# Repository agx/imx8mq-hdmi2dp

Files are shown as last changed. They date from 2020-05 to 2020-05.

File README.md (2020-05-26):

# HDMI to DP adapter for imx8mq

The imx8mq can output HDMI 2.0a or eDP/DP via it's HDMI TX. 
In order to test DisplayPort with a board that's designed
for HDMI one can use this adapter board. For this to work
you need to

- remove pull downs from the HDMI lanes. That's R1901-R1908 on the [Librem5 devkit][]
- use the DisplayPort instead of the HDMI firmware in uboot
  from https://www.nxp.com/lgfiles/NMG/MAD/YOCTO/firmware-imx-8.7.bin
- configure the Linux kernel for DP instead of HDMI for the cadence bridge
  as used in NXPs BSP:
  
```
&hdmi {
        compatible = "cdn,imx8mq-dp";
        lane-mapping = <0xc6>;
        status = "okay";
        port@1 {
                hdmi_in: endpoint {
                        remote-endpoint = <&dcss_out>;
                };
        };
};
```

The schematics for this kind of adapter were initially pubilshed by Bernhard
Fink from NXPs forum at https://community.nxp.com/thread/491629 .

[Librem5 devkit]: https://source.puri.sm/Librem5/dvk-mx8m-bsb

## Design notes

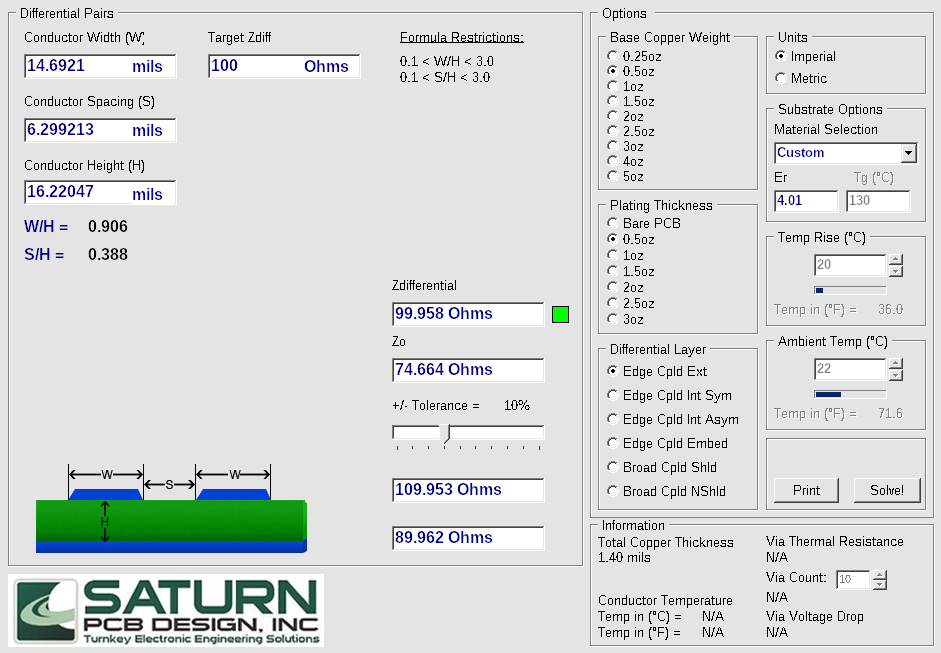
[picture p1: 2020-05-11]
calculations/saturn.png

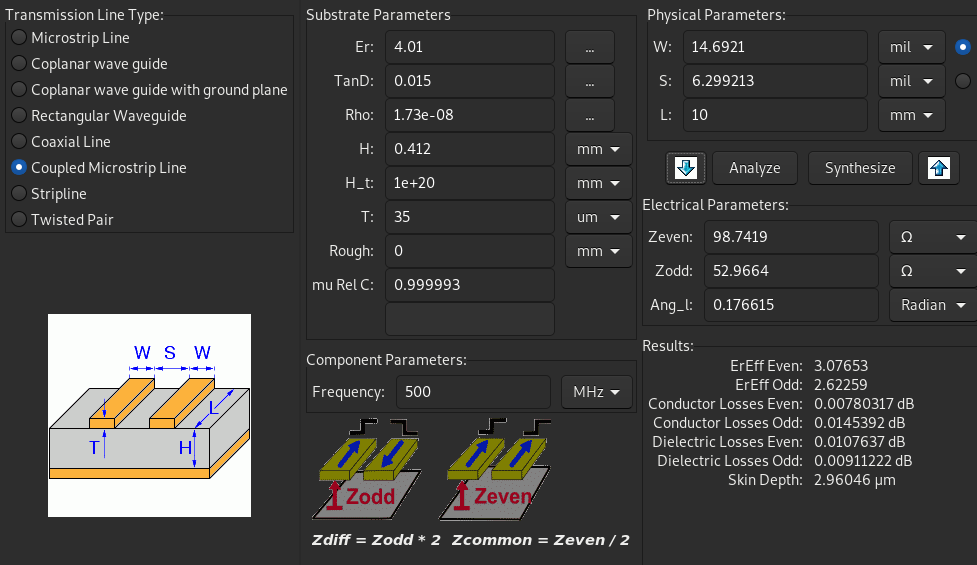
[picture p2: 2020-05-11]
calculations/kicad.png

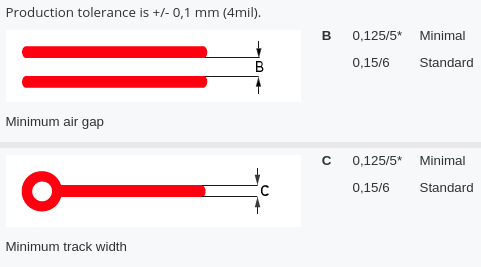
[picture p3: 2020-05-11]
calculations/minimum_trace_width_space.png

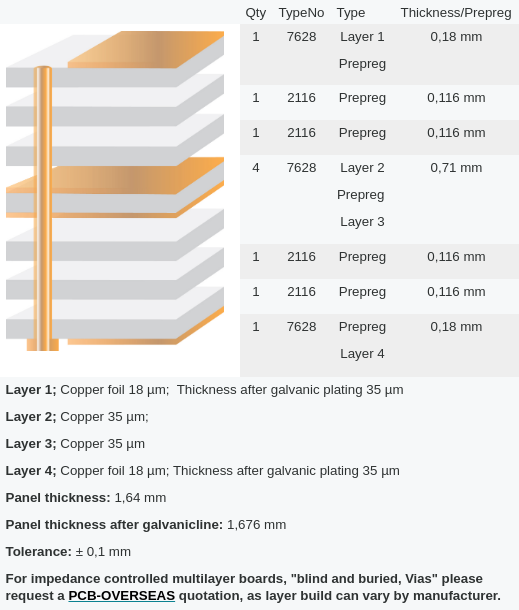
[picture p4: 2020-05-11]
calculations/stackup.png

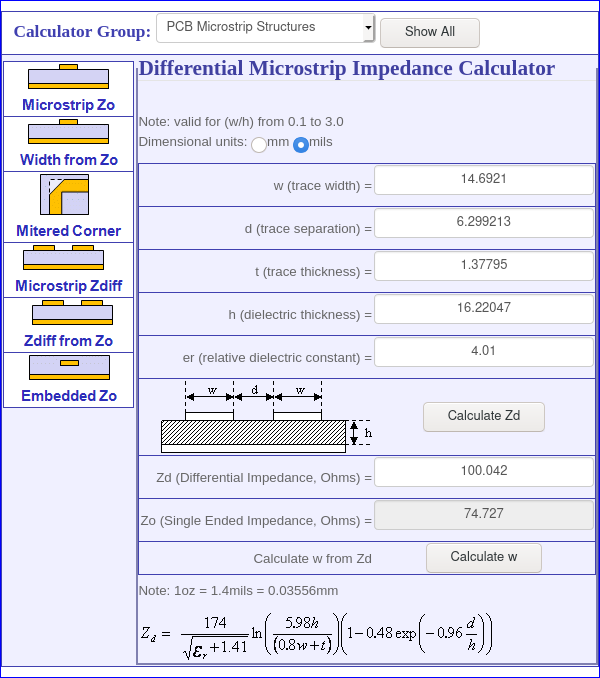
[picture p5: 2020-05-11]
calculations/mantaro.png

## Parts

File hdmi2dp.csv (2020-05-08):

Id | Designator | Package | Quantity | Designation | Supplier and ref
1 | J1 | AMPHENOL_10029449-001RLF | 1 | HDMI_A
2 | C1,C2,C3,C4,C6,C7,C8,C9,C10,C12,C13,C15,C16 | C_1206_3216Metric_Pad1.42x1.75mm_HandSolder | 13 | 0,1uF
3 | C5,C14 | C_1206_3216Metric_Pad1.42x1.75mm_HandSolder | 2 | 22uF
4 | C11 | C_1206_3216Metric_Pad1.42x1.75mm_HandSolder | 1 | 10uF
5 | J2 | MOLEX_47272-0001 | 1 | 47272-0001
6 | R1,R2,R6 | R_1206_3216Metric_Pad1.42x1.75mm_HandSolder | 3 | 1M
7 | U1 | SOT-223-3_TabPin2 | 1 | AMS1117-3.3
8 | C17 | C_1206_3216Metric_Pad1.42x1.75mm_HandSolder | 1 | 1uF
9 | R3,R7,R8 | R_1206_3216Metric_Pad1.42x1.75mm_HandSolder | 3 | >100K
10 | R4,R5 | R_1206_3216Metric_Pad1.42x1.75mm_HandSolder | 2 | 100K

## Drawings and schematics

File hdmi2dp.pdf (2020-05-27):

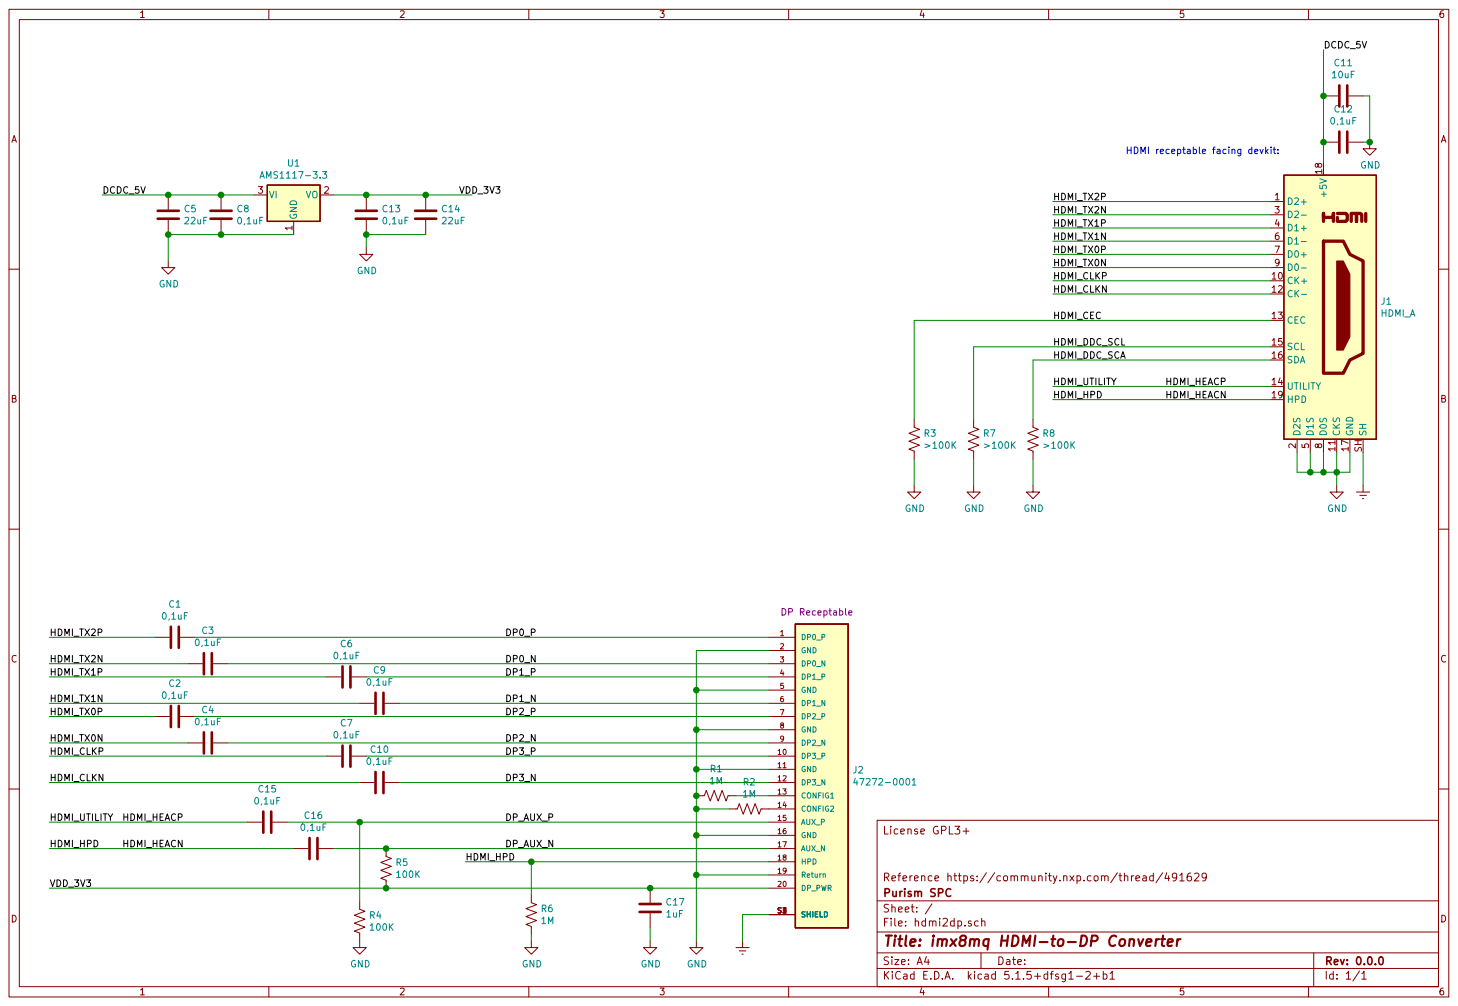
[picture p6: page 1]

HDMI receptable facing devkit:

Reference https://community.nxp.com/thread/491629
File: hdmi2dp.sch Sheet: / Purism SPC

Id: 1/1 Title: imx8mq HDMI-to-DP Converter

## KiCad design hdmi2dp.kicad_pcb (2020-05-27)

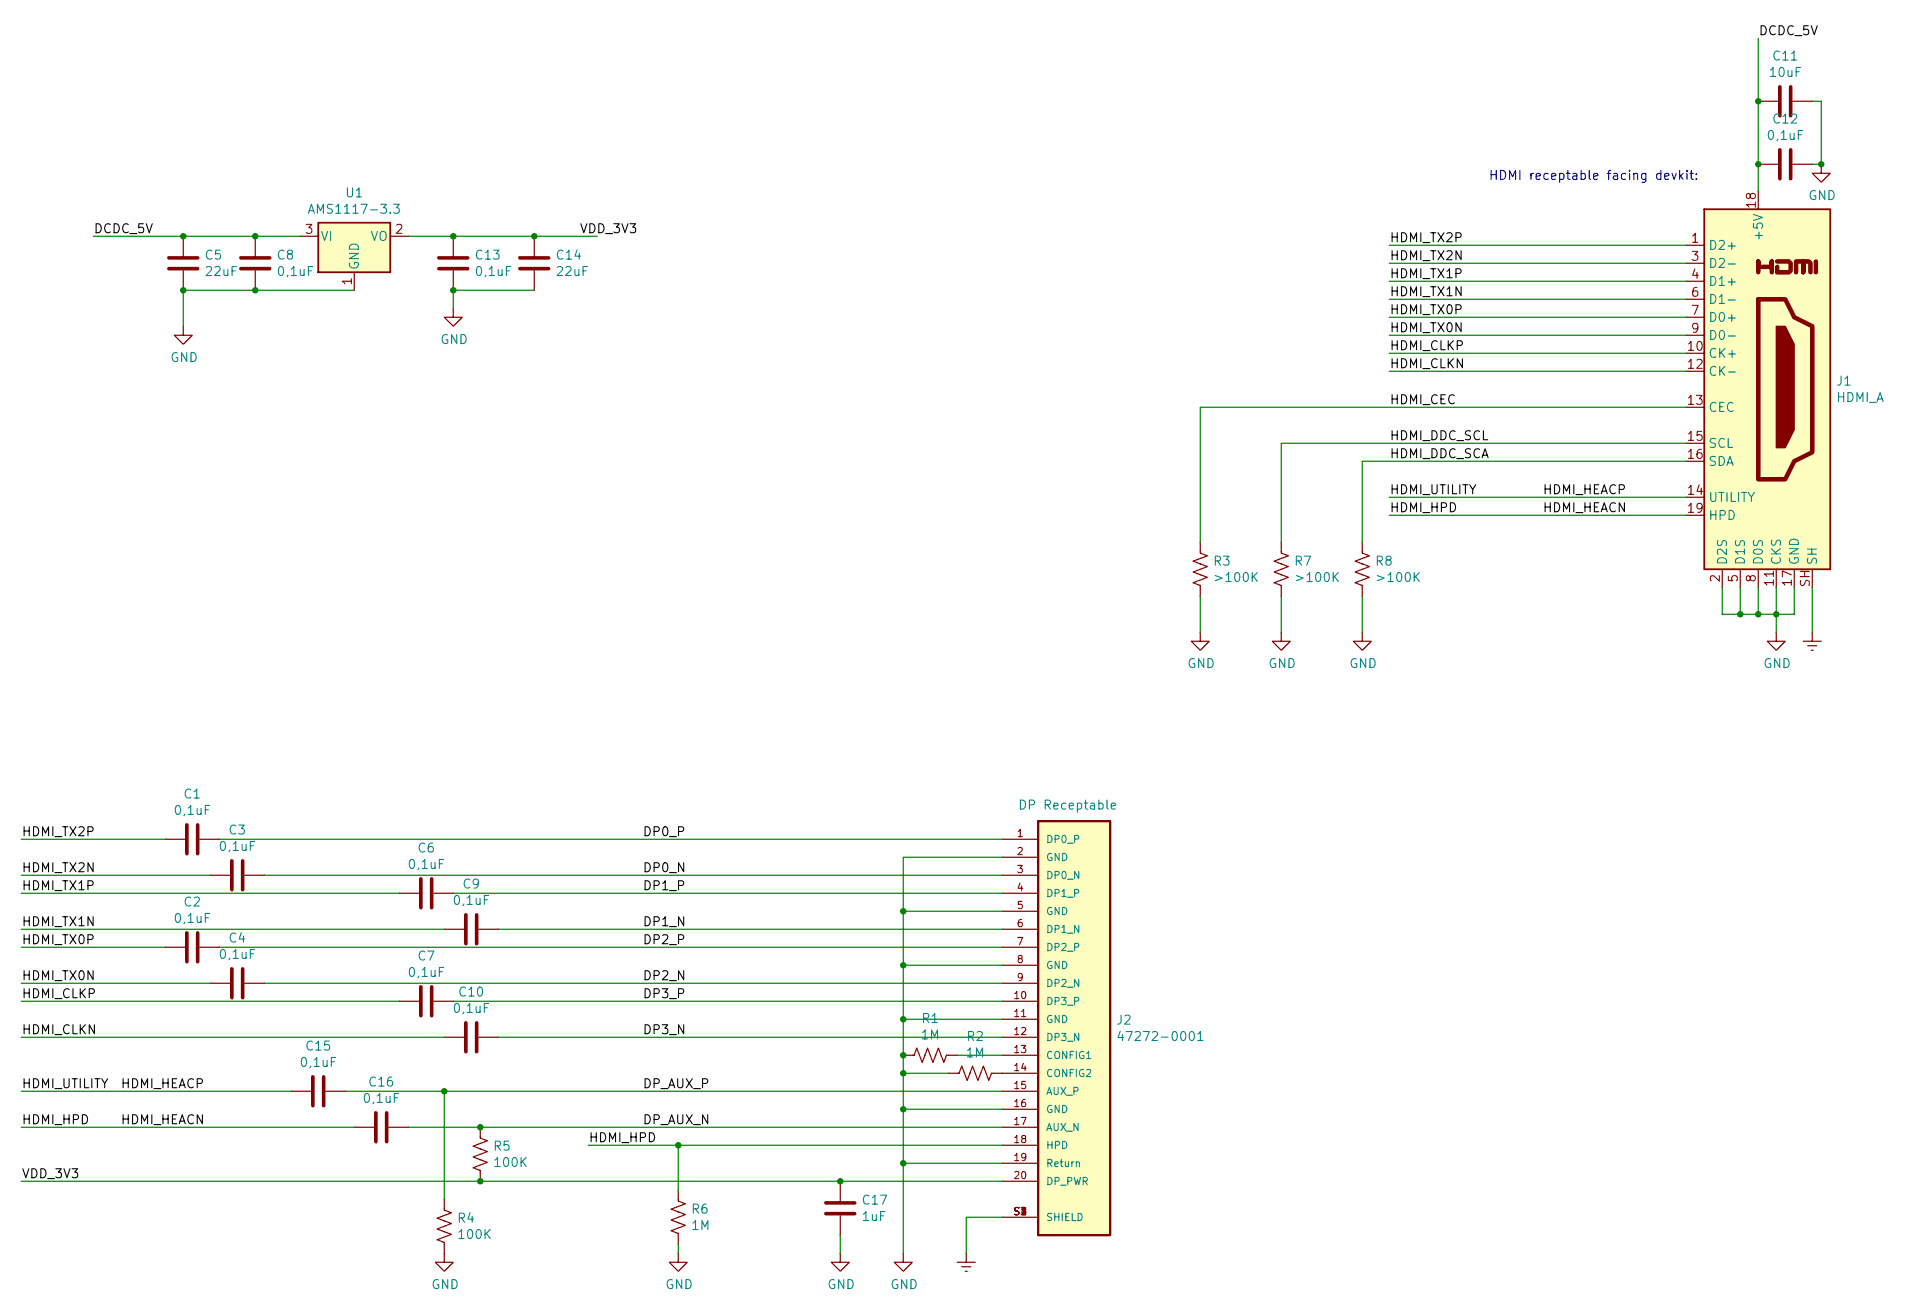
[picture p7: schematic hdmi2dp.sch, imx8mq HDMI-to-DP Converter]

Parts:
C1, C2, C3, C4, C6, C7, C8, C9, C10, C12, C13, C15, C16: 0,1uF; C_1206_3216Metric_Pad1.42x1.75mm_HandSolder
C5, C14: 22uF; C_1206_3216Metric_Pad1.42x1.75mm_HandSolder
C11: 10uF; C_1206_3216Metric_Pad1.42x1.75mm_HandSolder
C17: 1uF; C_1206_3216Metric_Pad1.42x1.75mm_HandSolder
J1: HDMI_A; AMPHENOL_10029449-001RLF
J2: 47272-0001; MOLEX_47272-0001
R1, R2, R6: 1M; R_1206_3216Metric_Pad1.42x1.75mm_HandSolder
R3, R7, R8: >100K; R_1206_3216Metric_Pad1.42x1.75mm_HandSolder
R4, R5: 100K; R_1206_3216Metric_Pad1.42x1.75mm_HandSolder
U1: AMS1117-3.3; SOT-223-3_TabPin2

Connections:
/DCDC_5V: C5.1, C8.1, C11.2, C12.2, J1.18 (+5V), U1.3 (VI)
/DP0_N: C3.1, J2.3 (DP0_N)
/DP0_P: C1.1, J2.1 (DP0_P)
/DP1_N: C9.1, J2.6 (DP1_N)
/DP1_P: C6.1, J2.4 (DP1_P)
/DP2_N: C4.1, J2.9 (DP2_N)
/DP2_P: C2.1, J2.7 (DP2_P)
/DP3_N: C10.1, J2.12 (DP3_N)
/DP3_P: C7.1, J2.10 (DP3_P)
/DP_AUX_N: C16.1, J2.17 (AUX_N), R5.1
/DP_AUX_P: C15.1, J2.15 (AUX_P), R4.1
/HDMI_CEC: J1.13 (CEC), R3.1
/HDMI_CLKN: C10.2, J1.12 (CK-)
/HDMI_CLKP: C7.2, J1.10 (CK+)
/HDMI_DDC_SCA: J1.16 (SDA), R8.1
/HDMI_DDC_SCL: J1.15 (SCL), R7.1
/HDMI_HEACN: C16.2, J1.19 (HPD), J2.18 (HPD), R6.1
/HDMI_HEACP: C15.2, J1.14 (UTILITY)
/HDMI_TX0N: C4.2, J1.9 (D0-)
/HDMI_TX0P: C2.2, J1.7 (D0+)
/HDMI_TX1N: C9.2, J1.6 (D1-)
/HDMI_TX1P: C6.2, J1.4 (D1+)
/HDMI_TX2N: C3.2, J1.3 (D2-)
/HDMI_TX2P: C1.2, J1.1 (D2+)
/VDD_3V3: C13.1, C14.1, C17.1, J2.20 (DP_PWR), R5.2, U1.2 (VO)
Earth: J1.S1, J1.S2, J1.S3, J1.S4, J1.SH, J2.S1 (SHIELD), J2.S2 (SHIELD), J2.S3 (SHIELD), J2.S4 (SHIELD)
GND: C5.2, C8.2, C11.1, C12.1, C13.2, C14.2, C17.2, J1.2 (D2S), J1.5 (D1S), J1.8 (D0S), J1.11 (CKS), J1.17 (GND), J2.2 (GND), J2.5 (GND), J2.8 (GND), J2.11 (GND), J2.16 (GND), J2.19 (Return), R1.2, R2.2, R3.2, R4.2, R6.2, R7.2, R8.2, U1.1 (GND)
unnamed: J2.13 (CONFIG1), R1.1
unnamed: J2.14 (CONFIG2), R2.1

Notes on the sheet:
HDMI receptable facing devkit:

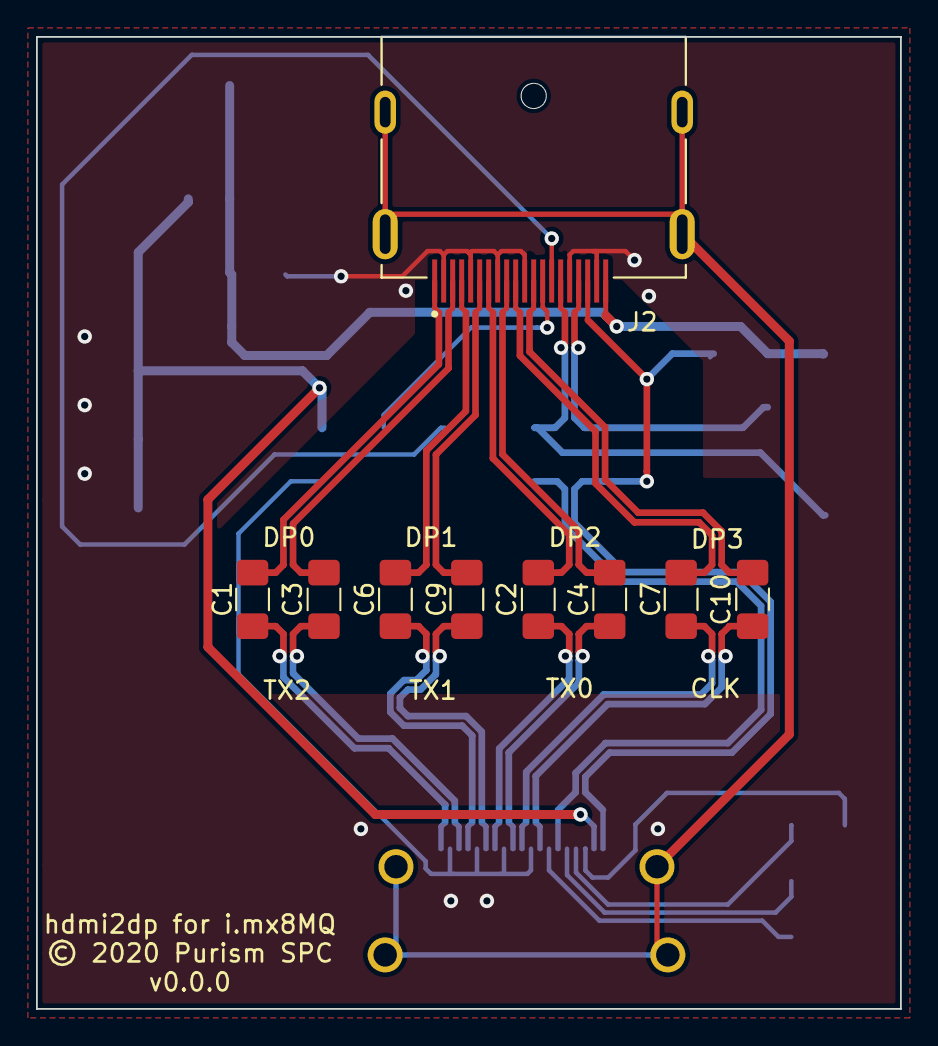
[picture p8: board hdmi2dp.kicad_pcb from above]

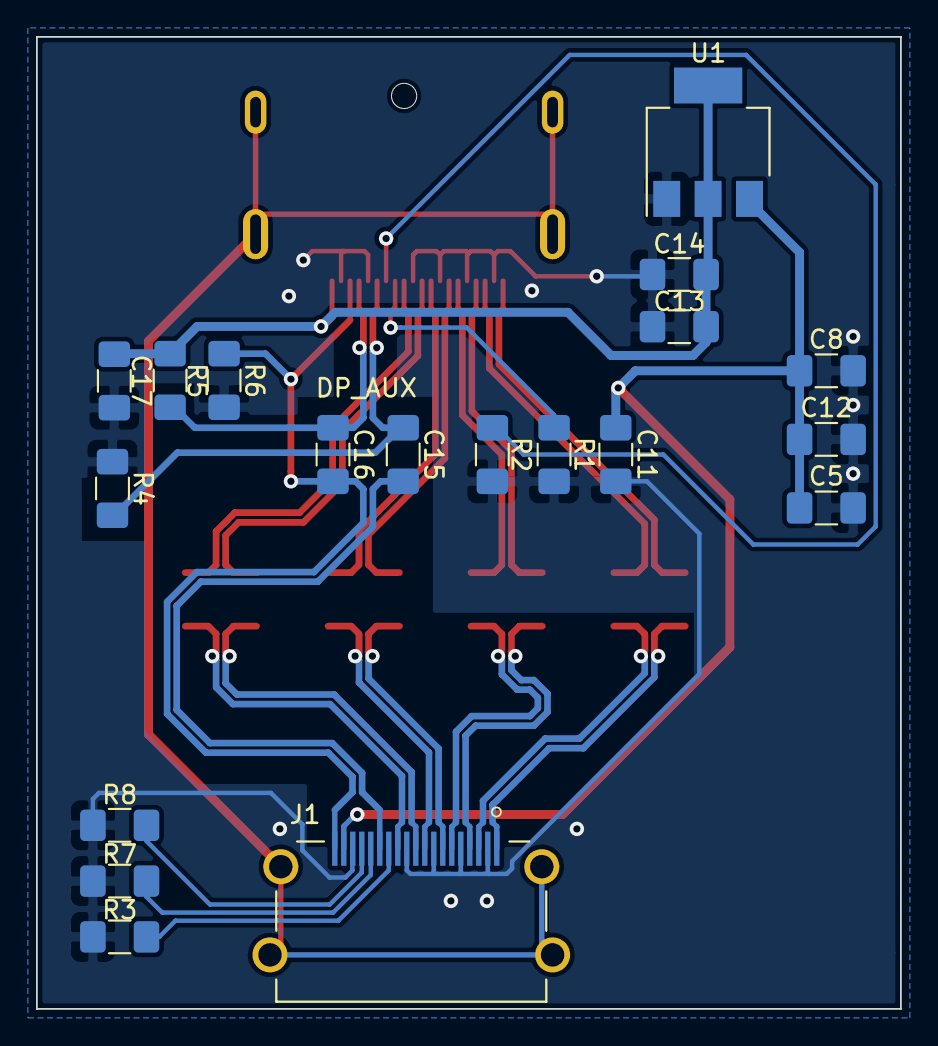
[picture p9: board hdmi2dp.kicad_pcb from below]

Board: 4 copper layers, 48.0 x 54.0 mm, 28 parts (19 on the bottom side), 29 nets.

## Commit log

2020-05-11 Reroute the diff pairs based on the impedance calculations using Beta Layout's stackup
    Also made the board 4 layers, fixed up the silkscreen, and added 3d models for the receptacles.
    [hdmi2dp.kicad_pcb]
2020-05-27 Add HDMI and DP lane pair names to silk screen
    [hdmi2dp.kicad_pcb]

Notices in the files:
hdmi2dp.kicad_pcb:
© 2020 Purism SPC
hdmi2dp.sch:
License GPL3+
